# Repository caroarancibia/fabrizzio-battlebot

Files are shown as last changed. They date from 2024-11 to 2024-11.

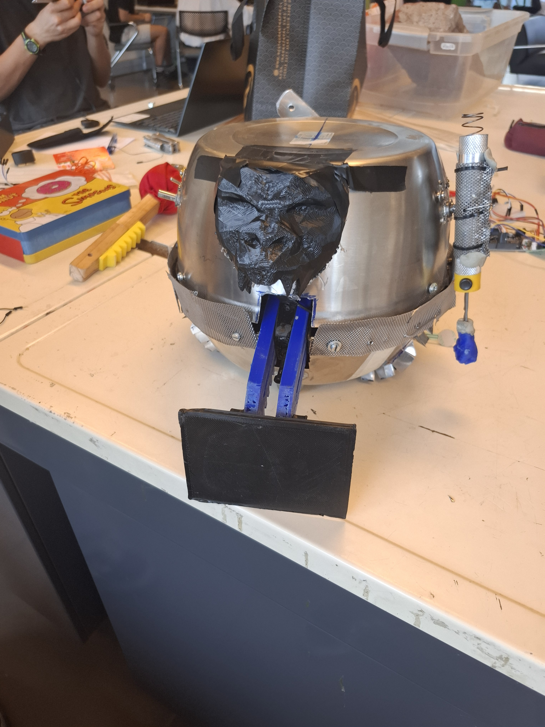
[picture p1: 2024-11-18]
multimedia/20241115_152734.jpg

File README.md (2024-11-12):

# Fabrizzio Battlebot - 2024 

### Historia del Battlebot
Oriundo de las junglas más bastas de las amazonas, Fabrizzio Parker, mejor conocido
como el “Mono Araña” emerge de su denso bioma en busca de venganza. Antes del
apocalipsis Fabrizzio y su amigo ranita vivían en plena armonía. Sin embargo, cuando
la guerra estallo, la destrucción arraso con todo a su paso. La rana en un acto de
heroísmo intento defender su morada, la jungla, fue brutalmente superada por fuerzas
enemigas. Fabrizzio lo encontró demasiado tarde, entre los restos de lo que una vez
fue su hogar.
Transformado por el dolor y la rabia Fabrizzio decidió en convertirse en “el mejor
jungla”. Equipo su arácnido cuerpo de 3 brazos giratorios que permiten atacar en todas
las direcciones de forma implacable, acompañado de una poderosa pala para cuidar
su radio y una velocidad propia de un insecto selvático. Cada golpe resuena con una
promesa de justicia para su amigo caído. 

## Integrantes
- Carolina Arancibia Moral - Facultad de Ciencias Físicas y Matemáticas
- Jefersson Chapilliquen García - Facultad de Ciencias Físicas y Matemáticas
- Diego Haro Montenegro - Facultad de Ciencias Físicas y Matemáticas
- Nicolas Wiertz Almendras - Facultad de Ciencias Físicas y Matemáticas

## Descripción del proyecto
  
### Estrategia utilizada
  
#### Ofensiva
Fabrizzio cuenta con un sistema de combate capaz de proteger todo su radio en todas
las direcciones Ya que posee 3 brazos estratégicamente posicionados para maximizar
su rango de ataque. Cada uno de ellos, está equipado con motores de 12v, un
mecanismo de retracción del largo y puños metálicos en cada uno de ellos.
Por otro lado, en el área frontal, en el área frontal, el robot cuenta con una pala
diseñada para cargar y lanzar a sus oponentes. Este mecanismo funciona mediante un
resorte de extensión y un motor de 12V. La pala está conectada a una pieza semicurva
acoplada al motor, que estira el resorte progresivamente. Cuando esta pieza alcanza
su punto máximo, se libera, permitiendo que el resorte se contraiga rápidamente y
eleve la pala con fuerza, generando el impulso necesario para arrojar al contrincante.

#### Defensiva
Estrategia defensiva: para poder defenderse, el robot cuenta con una gran capacidad de movimiento gracias a ruedas de bolas metálicas que permiten un control seguro y eficaz a la hora de evadir ataques. Por el otro lado, también cuenta con una pala que es explicada con detalle en el apartado de la estrategia ofensiva.

### Diagrama funcional
Diagrama de flujo (1)

## Licencia
<br />Esta obra está bajo una <a rel="license" href="http://creativecommons.org/licenses/by-nc/4.0/">Licencia Creative Commons Atribución-NoComercial 4.0 Internacional</a>.

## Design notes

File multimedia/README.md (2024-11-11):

# Archivos multimedia de los battlebots
- Foto del proyecto terminado

- Videos de demostración/funcionamiento:

https://github.com/user-attachments/assets/a68c29b8-e6ef-4145-a7ae-7567f00458a6

https://github.com/user-attachments/assets/8bfb0ece-a7ee-452e-99ac-e2b9e3a0b998

https://github.com/user-attachments/assets/80ca28c7-eb51-4621-aafe-5c7f440cd49e

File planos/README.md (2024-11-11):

# Archivos de planos 

Modelos y planos utilizados para construir el battlebot

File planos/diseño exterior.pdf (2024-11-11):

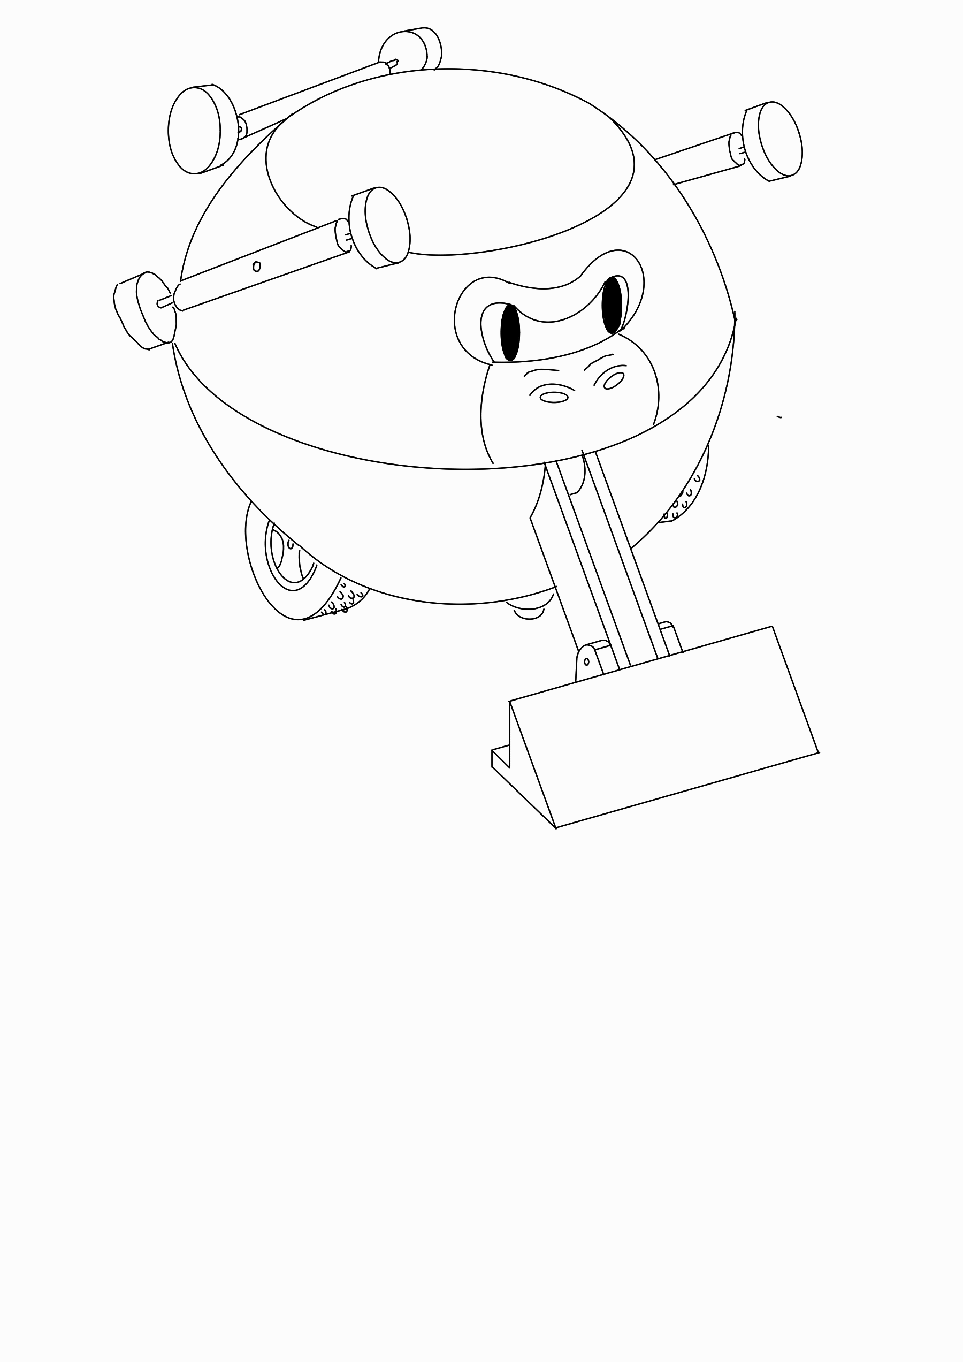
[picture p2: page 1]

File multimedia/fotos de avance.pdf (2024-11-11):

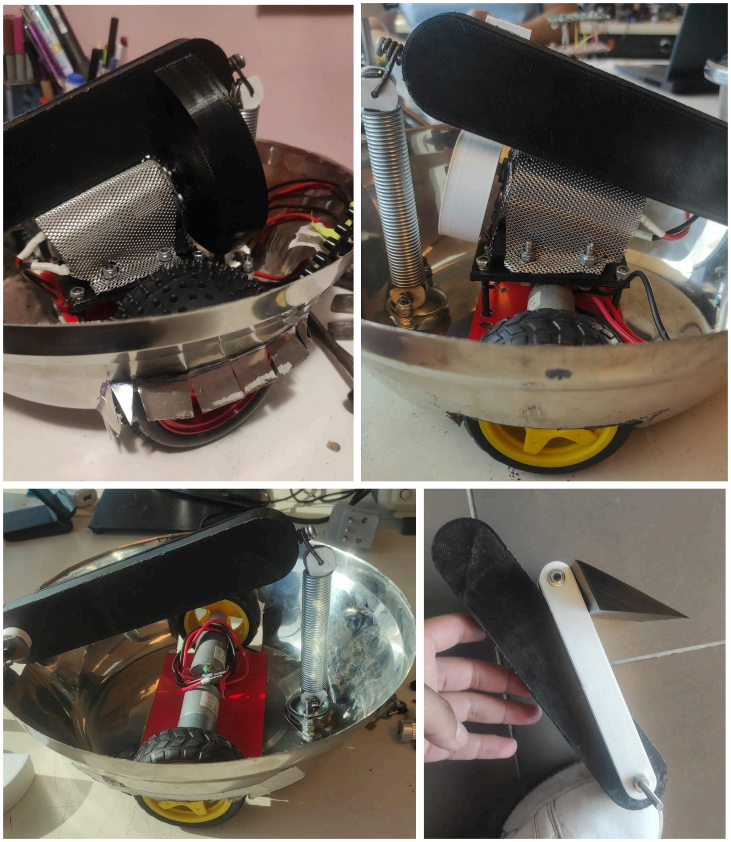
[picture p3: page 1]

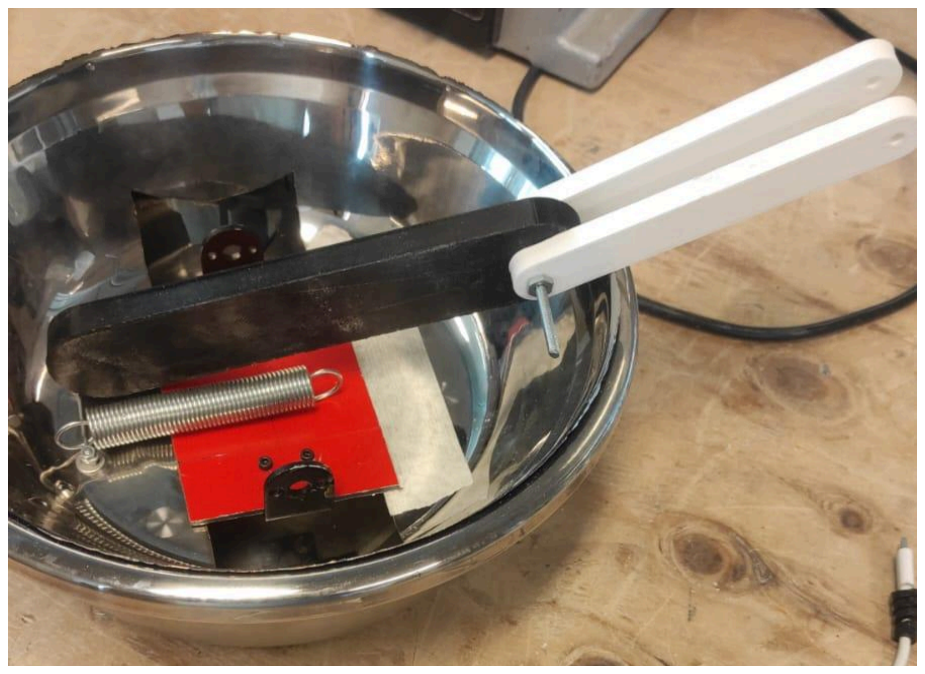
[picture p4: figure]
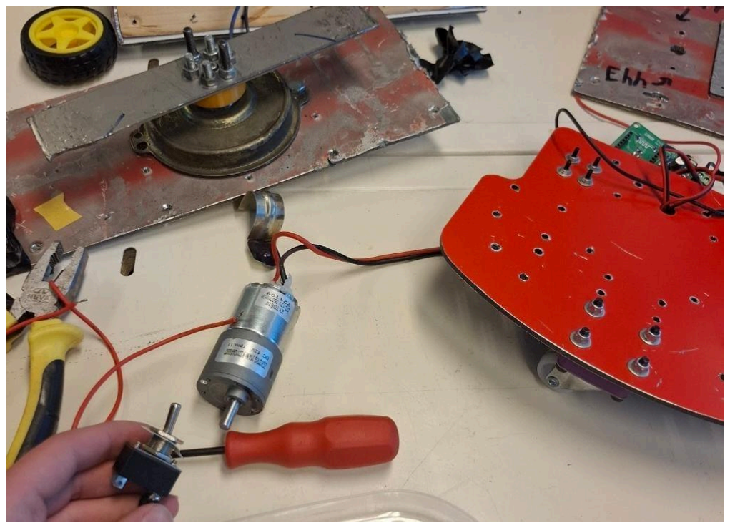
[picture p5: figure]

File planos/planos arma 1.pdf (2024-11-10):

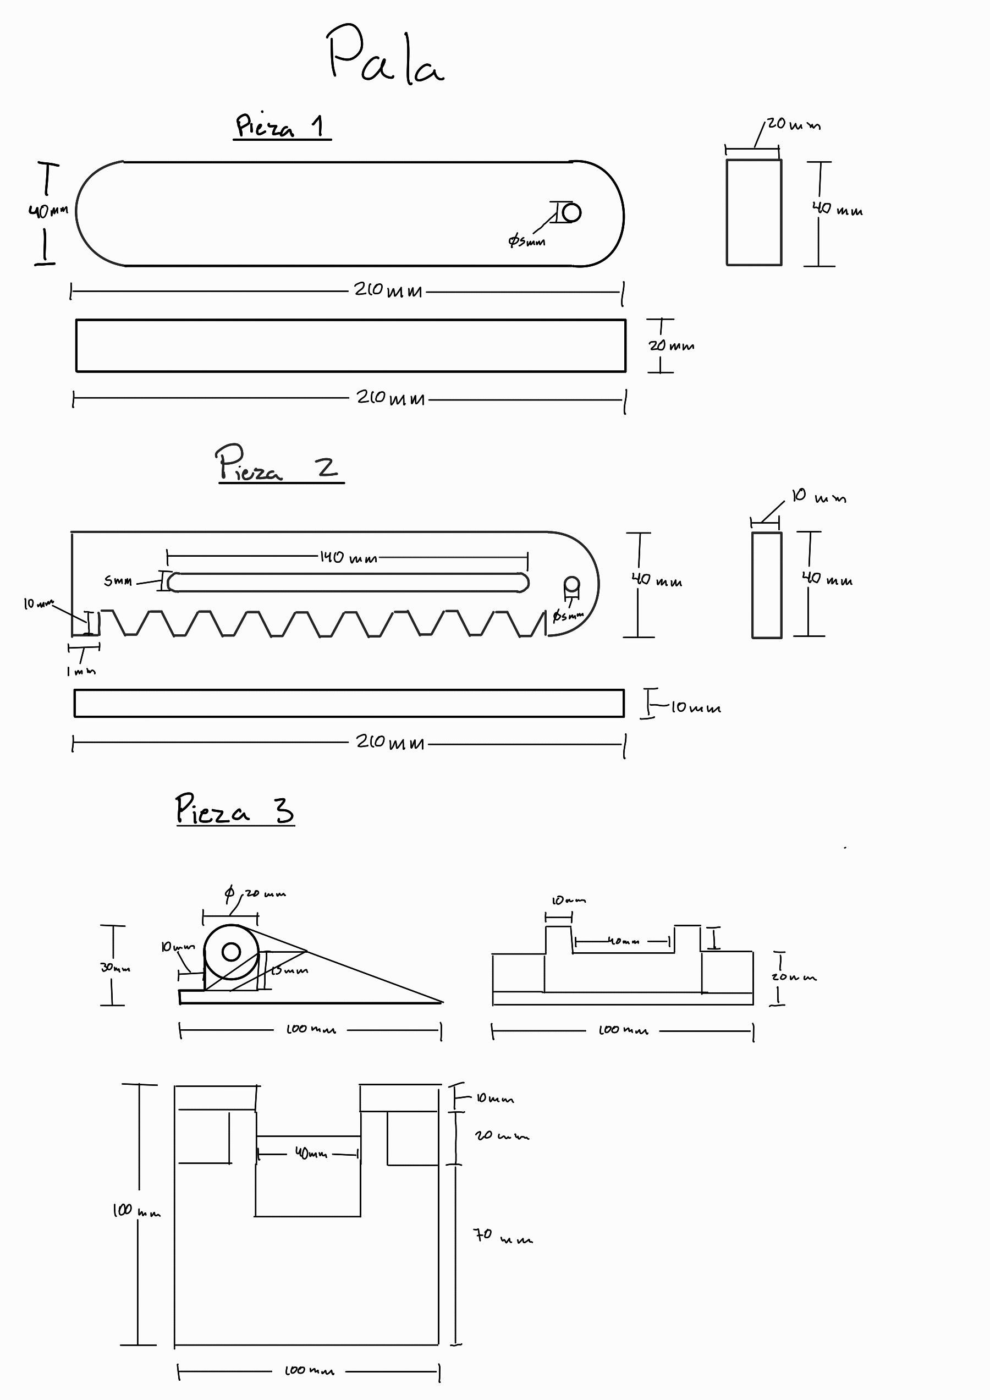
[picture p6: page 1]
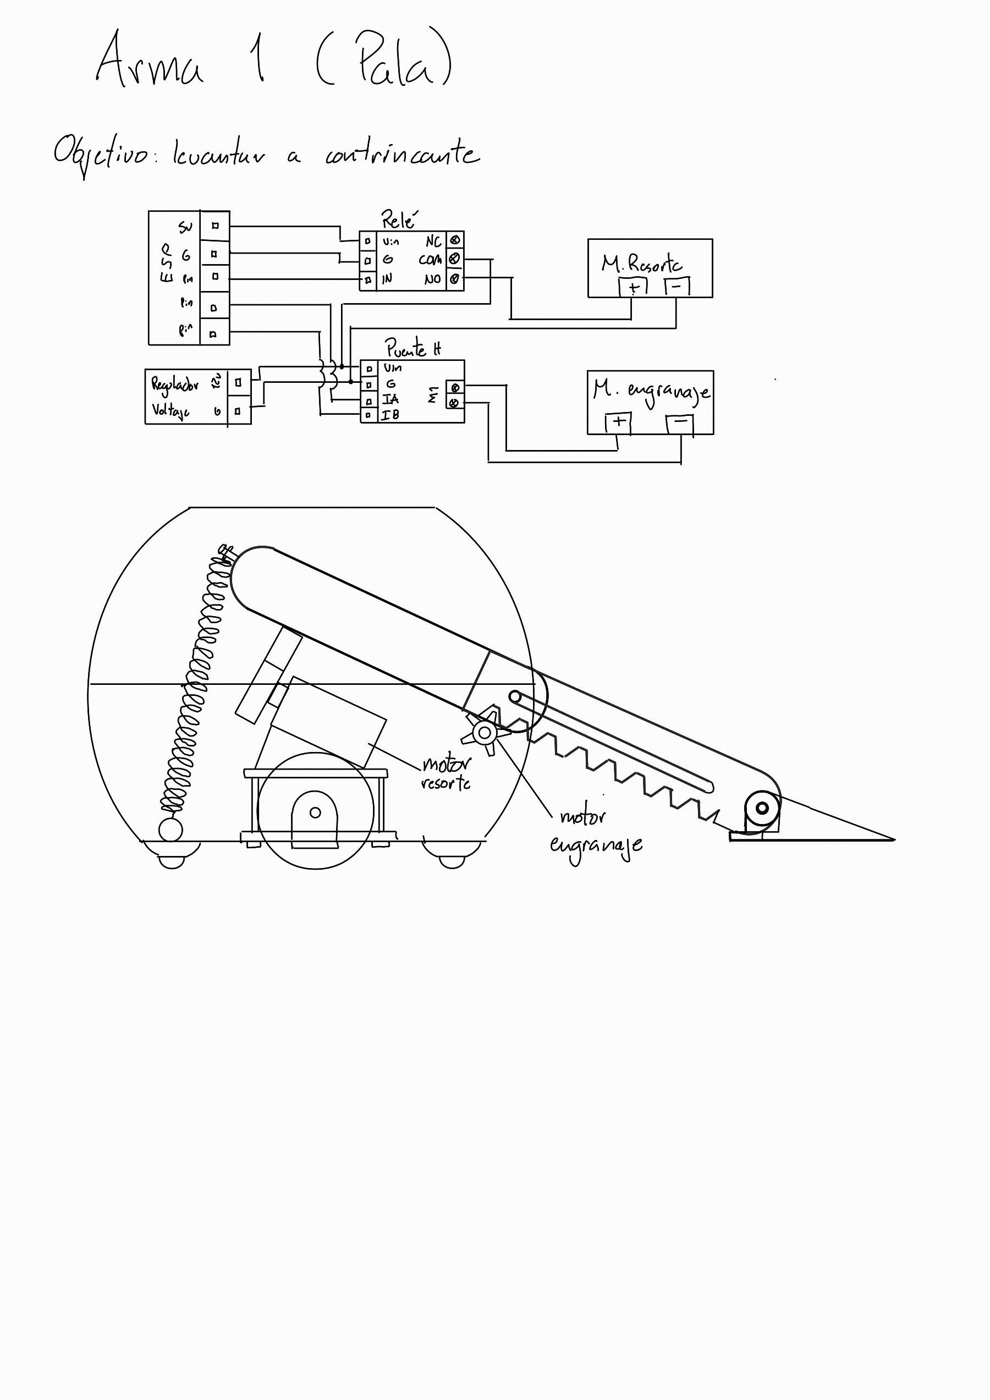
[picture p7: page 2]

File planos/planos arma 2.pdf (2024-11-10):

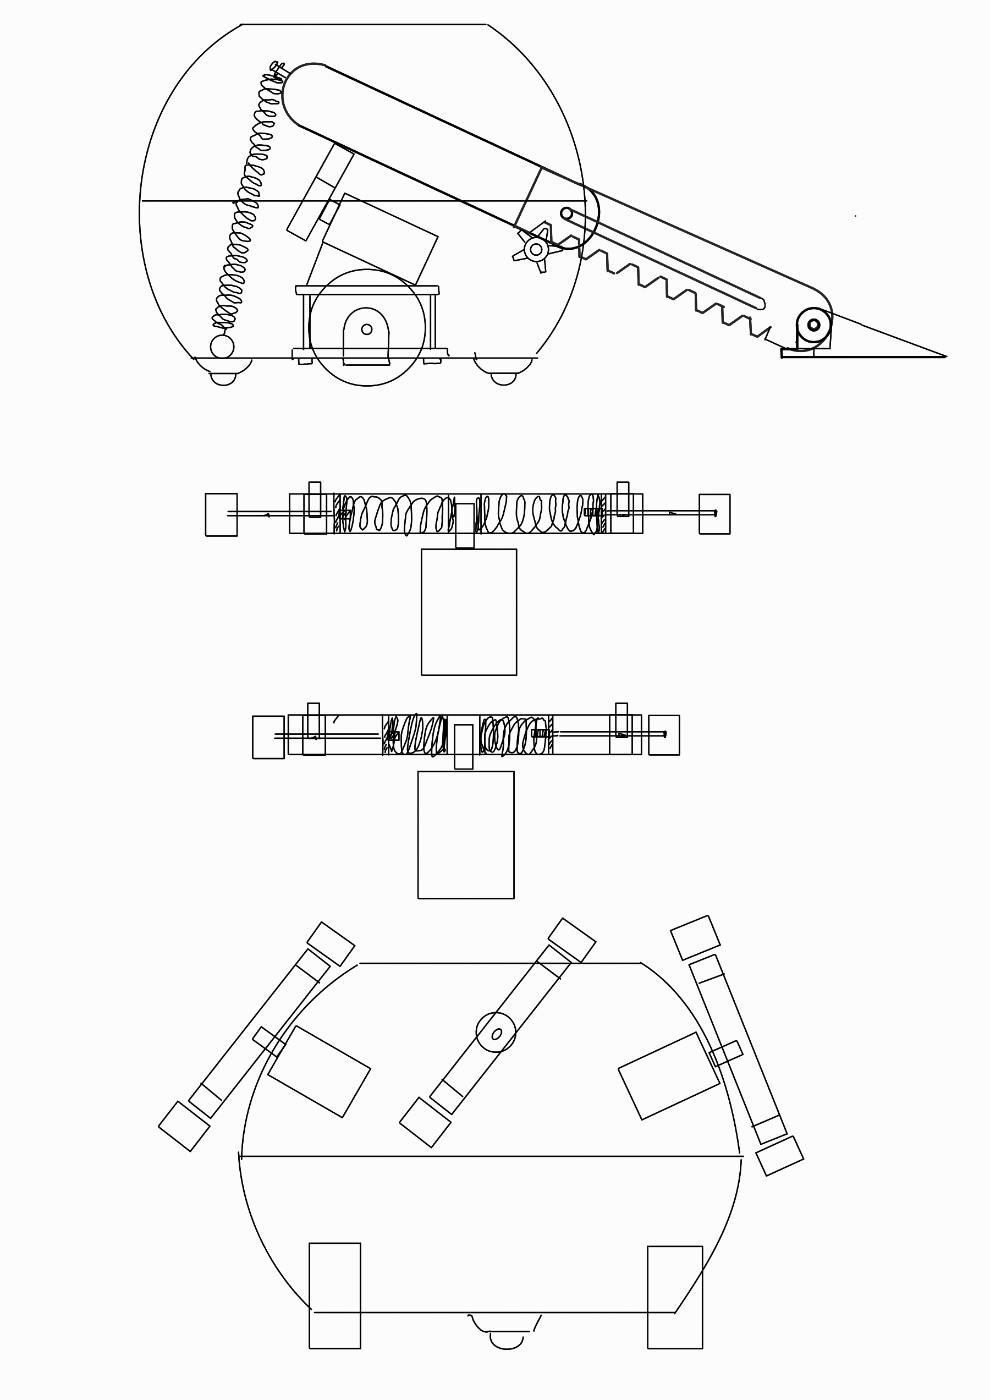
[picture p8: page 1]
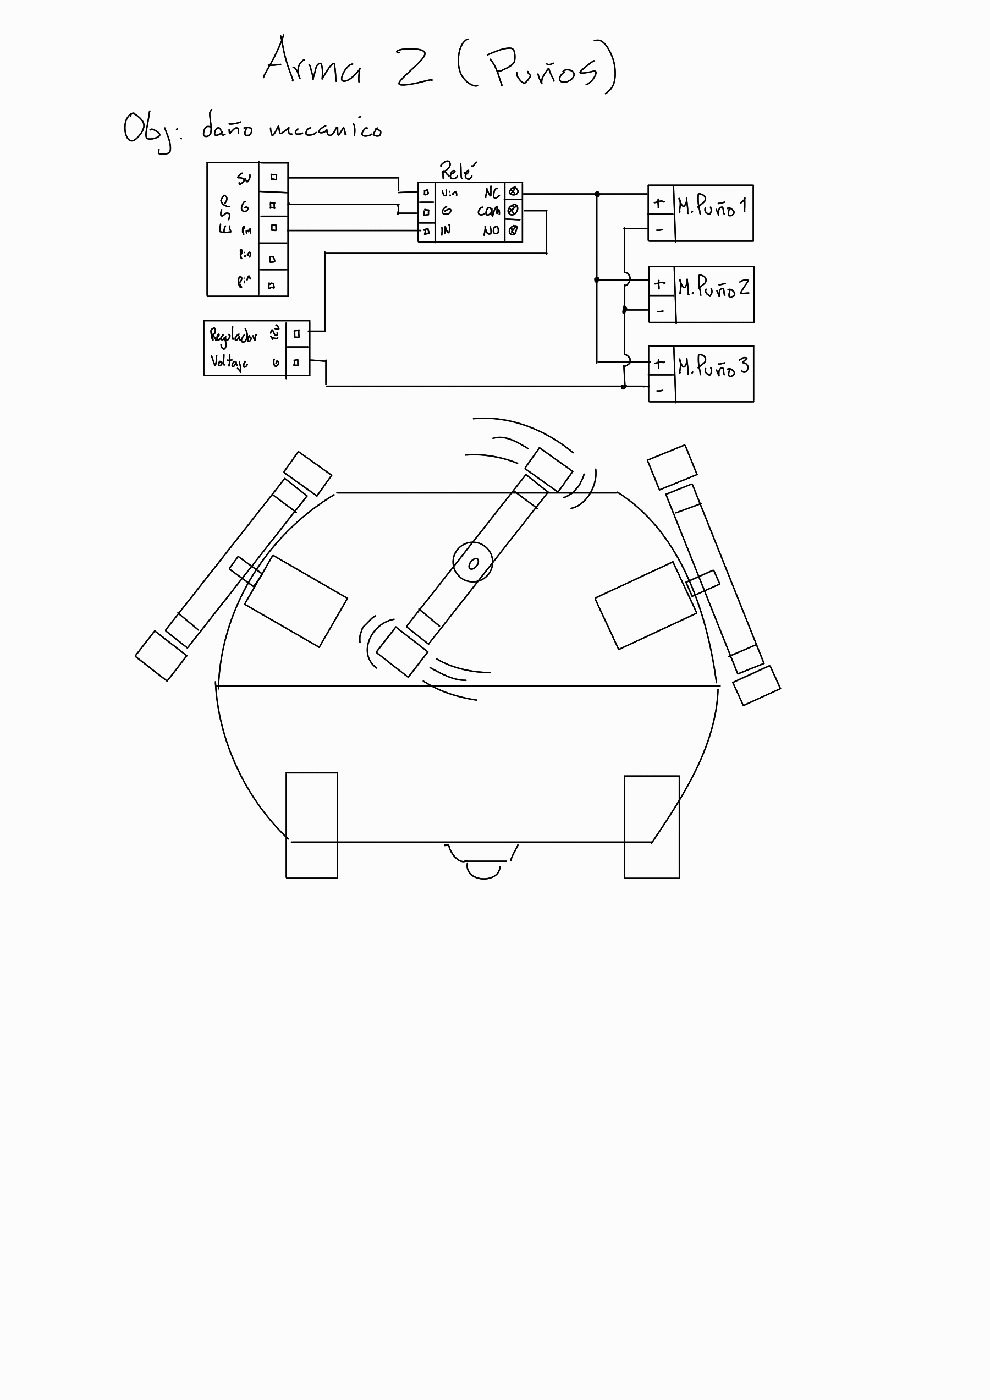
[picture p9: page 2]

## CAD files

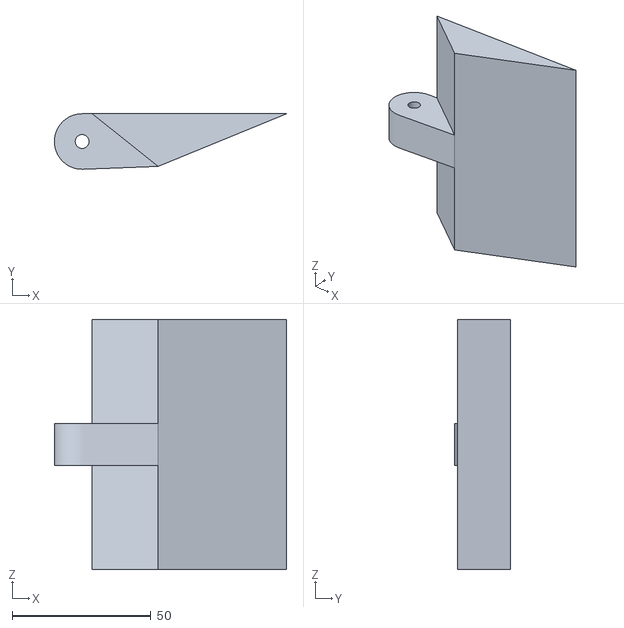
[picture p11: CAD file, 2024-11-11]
planos/pieza pala.stl
83.6 x 20.0 x 90.0

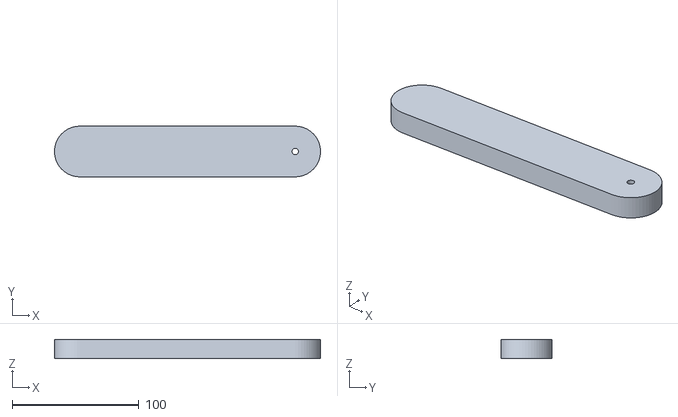
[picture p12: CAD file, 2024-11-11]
planos/pieza 2 arma 2.stl
209.9 x 40.0 x 15.0

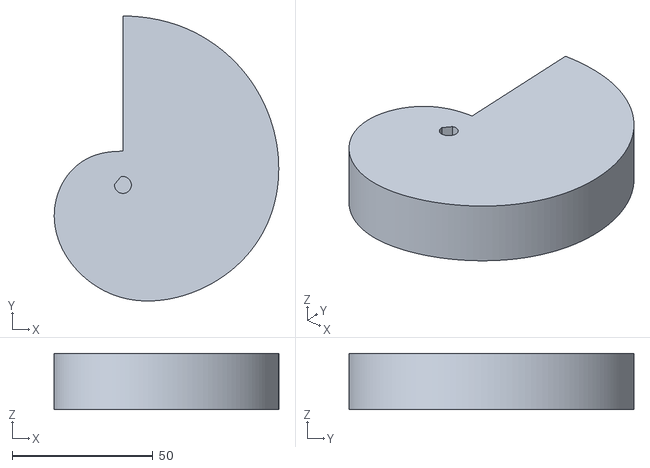
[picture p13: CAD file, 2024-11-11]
planos/pieza caracol pala.stl
79.7 x 101.2 x 20.0

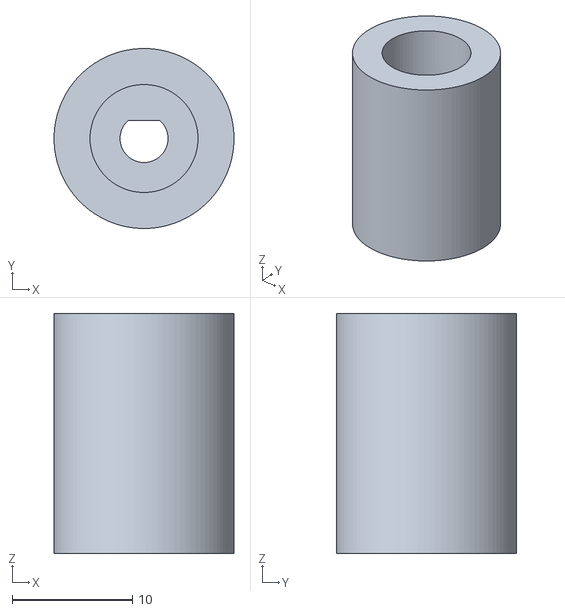
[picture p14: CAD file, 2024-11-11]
planos/pieza union rueda.stl
15.0 x 15.0 x 20.0

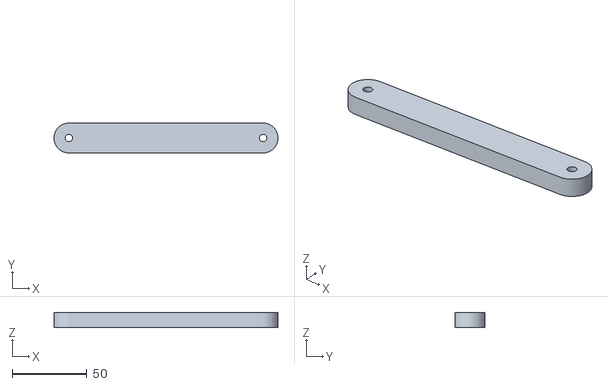
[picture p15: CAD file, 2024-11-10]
planos/pieza 3 arma 2.stl
150.0 x 20.0 x 10.0

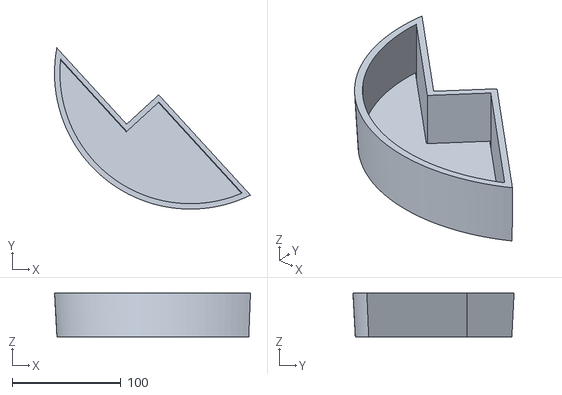
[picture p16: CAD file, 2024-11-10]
planos/caja base I.stl
180.2 x 148.2 x 40.0

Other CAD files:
planos/caja base D.stl

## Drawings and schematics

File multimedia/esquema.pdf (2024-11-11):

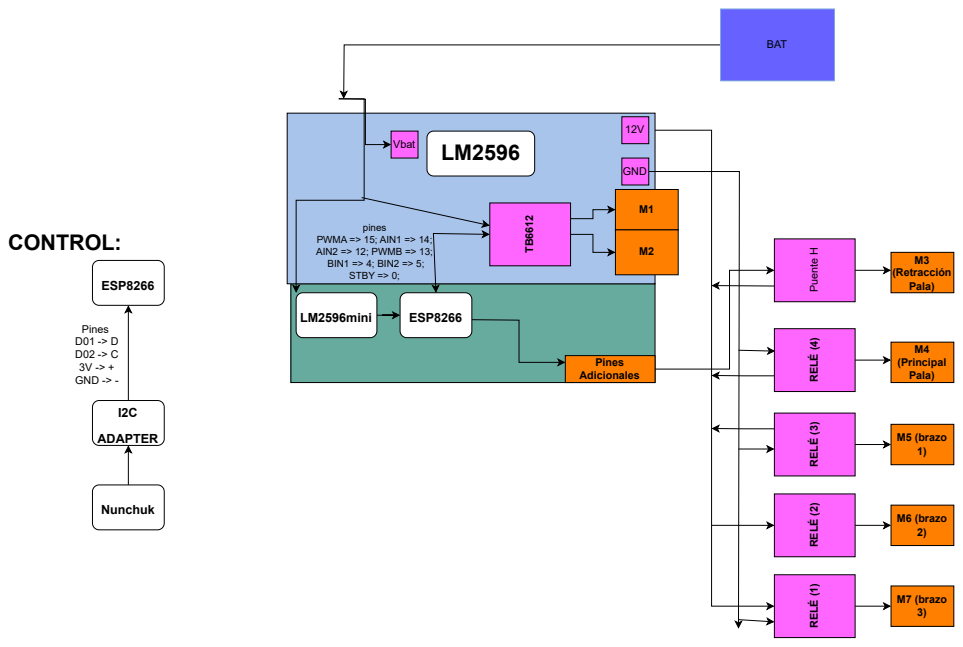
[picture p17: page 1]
BAT; GND; Vbat; LM2596mini; ESP8266; Pines Adicionales; Nunchuk; ADAPTER; Pines D01 -> D D02 -> C 3V -> + GND -> -; CONTROL:; pines PWMA => 15; AIN1 => 14; AIN2 => 12; PWMB => 13; BIN1 => 4; BIN2 => 5; STBY => 0;; M3 (Retracción Pala); M4 (Principal Pala); M5 (brazo 1); M6 (brazo 2); M7 (brazo 3)

RELÉ (1) RELÉ (2) RELÉ (3) RELÉ (4) Puente H
